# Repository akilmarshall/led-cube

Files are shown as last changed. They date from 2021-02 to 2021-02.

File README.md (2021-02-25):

# LED Cube

A library to control a class of led cubes of my own design.
Using ws2811 led's connected serially.

big thanks to iyassou's [matrix multiplication library](https://github.com/iyassou/umatrix) for micropython

## Theory

## Build Instructions

The forms can be 3D printed on an FFF printer at 0.3mm or finer layer height, no infill required.
The vertical form may cause quite a lot of stringing.

First use the horizontal form and solder together "sticks" of leds connecting the ground and power pins forming rails.
Then chain the din and dout pins of each led in the stick linearly connecting them.
For a 3x3x3 led cube one will assemble 9 led sticks.

Then use the vertical form to assemble led sticks into "walls", soldering together the ground and power rails.
For a 3x3x3 leds one will use 3 sticks and assemble 1 of 3 walls.

solder together the walls connecting the ground and power connections between them.

finally linearly solder the sticks together (din -> dout)

## API

The color of each led is tracked in Cube._state

```
Cube.set((x, y, z), (g, r, b))
```
the set method modifies Cube._state.

```
Cube.update()
```
the update method uses the information withing Cube._state and writes to the cube. 

```
Cube.fill((g, r, b))
```
writes the color (g, r, b) to each led in the cube.
Cube._state is not modified.

```
Cube.clear()
```
Shorthand for Cube.fill((0, 0, 0))

```
Cube.rotate_x()
Cube.rotate_y()
Cube.rotate_z()
```
Rotates Cube._state pi/2 counterclockwise about the specified central axis.
Computes the new positions using [homogenous coordinate transforms](https://www.cs.brandeis.edu/~cs155/Lecture_07_6.pdf).

```
Cube._map_update(A)
# A is a 4x4 homogenous matrix
```
A helper method to update each position using the matrix A.

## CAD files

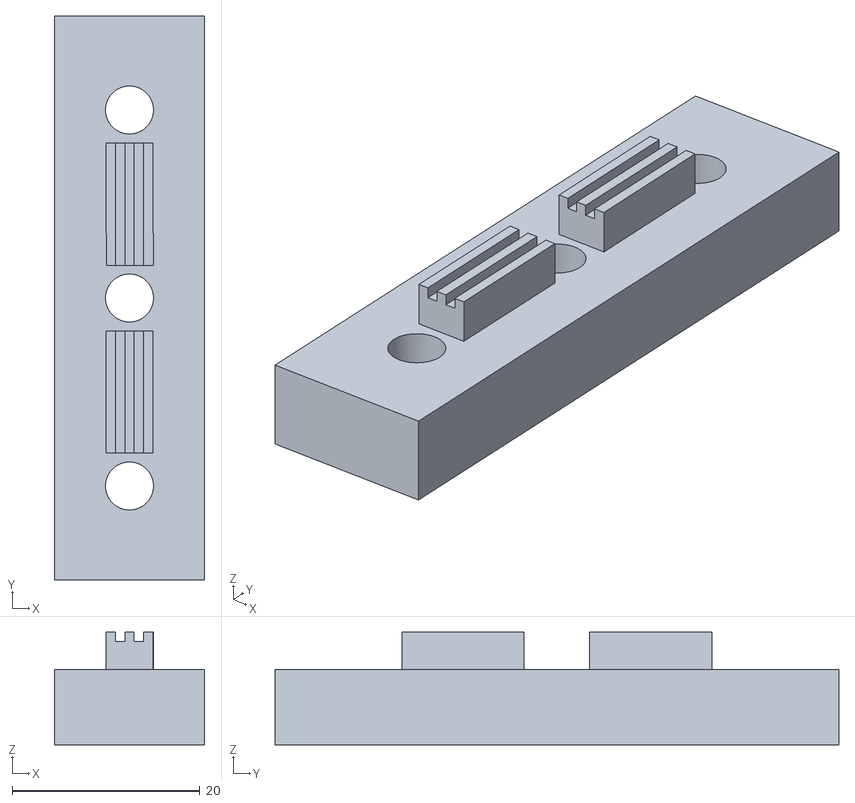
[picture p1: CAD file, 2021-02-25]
models/horizontal_form.stl
16.0 x 60.0 x 12.0

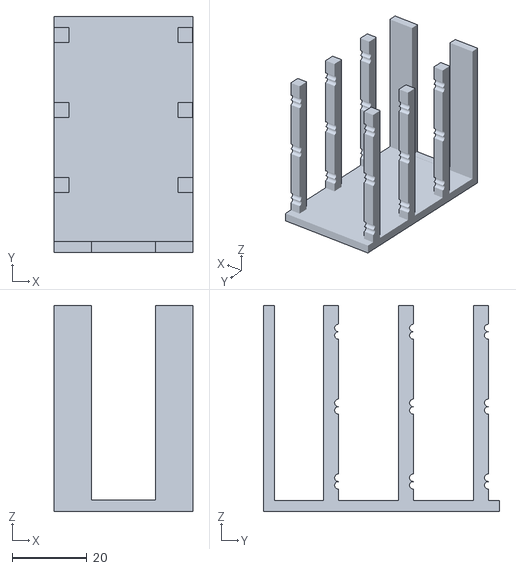
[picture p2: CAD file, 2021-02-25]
models/vertical_form.stl
37.0 x 63.0 x 55.0

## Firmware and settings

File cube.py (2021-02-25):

import time
from machine import Pin
from neopixel import NeoPixel
from random import randint, choice
from time import sleep_ms
from umatrix import matrix
from math import cos, sin, pi


n = 27


def demo(np, r, b, g):
    n = np.n
    np.fill((0, 0, 0))
    np.write()
    time.sleep_ms(1000)

    for i in range(n):
        np[i] = (r, b, g)
        np.write()
        time.sleep_ms(100)


def run(t):
    np = NeoPixel(Pin(13), n, timing=t)
    demo(np, 255, 0, 0)
    demo(np, 0, 255, 0)
    demo(np, 0, 0, 255)
    demo(np, 255, 255, 255)
    np.fill((0, 0, 0))
    np.write()


def to_homogeneous(point):
    # takes a 3-tuple and returns a related homogeneous vector
    x, y, z = point
    return matrix([x, y, z, 1], are_rows=False)


def from_homogeneous(vector):
    # takes a homogenous vector and returns a 3-tuple
    x = vector[0][0]
    y = vector[1][0]
    z = vector[2][0]
    return (x, y, z)


class Cube:
    def __init__(self, n=27, pin=13):
        # n leds
        self._n = n
        # control pin on the microcontroller
        self._pin = pin

        self._np = NeoPixel(Pin(self._pin), self._n)

        # (x, y, z) -> i, where i is the linear index
        self._mapping = {
            (0, 0, 0): 0,
            (1, 0, 0): 1,
            (2, 0, 0): 2,
            (2, 0, 1): 3,
            (1, 0, 1): 4,
            (0, 0, 1): 5,
            (0, 0, 2): 6,
            (1, 0, 2): 7,
            (2, 0, 2): 8,
            (0, 1, 0): 9,
            (1, 1, 0): 10,
            (2, 1, 0): 11,
            (2, 1, 1): 12,
            (1, 1, 1): 13,
            (0, 1, 1): 14,
            (0, 1, 2): 15,
            (1, 1, 2): 16,
            (2, 1, 2): 17,
            (0, 2, 0): 18,
            (1, 2, 0): 19,
            (2, 2, 0): 20,
            (2, 2, 1): 21,
            (1, 2, 1): 22,
            (0, 2, 1): 23,
            (0, 2, 2): 24,
            (1, 2, 2): 25,
            (2, 2, 2): 26
        }

        # maintain a color state for each point in the cube
        # this acts as the preimage for transforms of the cube, i.e. rotations, translations, etc
        self._state = dict()
        for i in range(3):
            for j in range(3):
                for k in range(3):
                    self._state[(i, j, k)] = (0, 0, 0)

    def update(self):
        # realizes self._state on to the cube
        for point in self._state:
            color = self._state[point]
            self._np[self._mapping[point]] = color

        self._np.write()

    def fill(self, color):
        g, r, b = color
        self._np.fill((g, r, b))
        self._np.write()

    def clear(self):
        # short hand to fill with (0, 0, 0)
        self.fill((0, 0, 0))

    def set(self, pos, col):
        # pos is a 3 tuple
        # col is an grb tuple
        self._state[pos] = col

    def _map_update(self, A):
        # compute a new self._state by matrix multiplying each position by A
        new_state = {}

        for point in self._state:
            color = self._state[point]
            point_new = A * to_homogeneous(point)
            new_state[from_homogeneous(point_new)] = color

        self._state = new_state

    def rotate_z(self):
        # rotate about the central z axis pi/2 counterclockwise
        theta = pi/2
        T = matrix([1, 0, 0, -1],
                   [0, 1, 0, -1],
                   [0, 0, 1, 0],
                   [0, 0, 0, 1])
        Tinv = matrix([1, 0, 0, 1],
                      [0, 1, 0, 1],
                      [0, 0, 1, 0],
                      [0, 0, 0, 1])
        M = matrix([round(cos(theta)), round(-sin(theta)), 0, 0],
                   [round(sin(theta)), round(cos(theta)), 0, 0],
                   [0, 0, 1, 0],
                   [0, 0, 0, 1])

        # transformation matrix
        A = Tinv * M * T
        self._map_update(A)

    def rotate_x(self):
        # rotate about the central x axis pi/2 counterclockwise
        theta = pi/2
        T = matrix([1, 0, 0, 0],
                   [0, 1, 0, -1],
                   [0, 0, 1, -1],
                   [0, 0, 0, 1])
        Tinv = matrix([1, 0, 0, 0],
                      [0, 1, 0, 1],
                      [0, 0, 1, 1],
                      [0, 0, 0, 1])
        M = matrix([1, 0, 0, 0],
                   [0, round(cos(theta)), round(-sin(theta)), 0],
                   [0, round(sin(theta)), round(cos(theta)), 0],
                   [0, 0, 0, 1])

        # transformation matrix
        A = Tinv * M * T
        self._map_update(A)

    def rotate_y(self):
        # rotate about the central y axis pi/2 counterclockwise
        theta = pi/2
        T = matrix([1, 0, 0, -1],
                   [0, 1, 0, 0],
                   [0, 0, 1, -1],
                   [0, 0, 0, 1])
        Tinv = matrix([1, 0, 0, 1],
                      [0, 1, 0, 0],
                      [0, 0, 1, 1],
                      [0, 0, 0, 1])
        M = matrix([round(cos(theta)), 0, round(-sin(theta)), 0],
                   [0, 1, 0, 0],
                   [round(sin(theta)), 0, round(cos(theta)), 0],
                   [0, 0, 0, 1])

        # transformation matrix
        A = Tinv * M * T
        self._map_update(A)

    def cross(self):
        self.set((1, 1, 0), (10, 0, 0))
        self.set((1, 1, 2), (10, 0, 0))

        self.set((1, 0, 1), (0, 10, 0))
        self.set((1, 2, 1), (0, 10, 0))

        self.set((0, 1, 1), (0, 0, 10))
        self.set((2, 1, 1), (0, 0, 10))

        self.set((1, 1, 1), (10, 10, 10))

        self.update()

    def random_demo(self):
        colors = [(10, 0, 0), (0, 10, 0), (0, 0, 10),
                  (10, 10, 0), (10, 0, 10), (0, 10, 10)]
        on = []
        while True:
            for _ in range(5):
                point = choice(list(self._mapping.keys()))
                color = choice(colors)
                on.append((point, color))

            for p, c in on:
                self.set(p, c)

            self.write()
            sleep_ms(200)
            self.clear()
            on.clear()

    def random_rotations(self):
        colors = [(10, 0, 0), (0, 10, 0), (0, 0, 10),
                  (10, 10, 0), (10, 0, 10), (0, 10, 10)]

        rotations = [self.rotate_x, self.rotate_y, self.rotate_z]
        # turn on 5 random points
        for _ in range(5):
            point = choice(list(self._mapping.keys()))
            color = choice(colors)
            self.set(point, color)

        self.update()
        sleep_ms(1000)

        while True:
            r = choice(rotations)
            r()
            self.update()
            t = choice(range(3000))
            sleep_ms(t)
